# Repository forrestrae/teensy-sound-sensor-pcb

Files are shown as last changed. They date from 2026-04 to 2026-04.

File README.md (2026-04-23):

# Sound Sensor Teensy Carrier

A KiCad 9.0 carrier board for the Teensy 4.x microcontroller, designed for real-time audio sensing with USB-C Power Delivery input, 4S Li-ion battery management, I2S MEMS microphone, and LED lighting outputs.

## Features

- **USB-C Power Delivery** — TPS25751 PD controller with EEPROM configuration; accepts standard 5 V USB or negotiated PD voltages
- **4S Li-ion Battery System** — BQ25798 charger, BQ7791500 multi-cell protection (30 A rated), and Infineon N-channel disconnect FET
- **Regulated Power Rails** — 5 V and 3.3 V via TPS54538 synchronous buck converter
- **I2S MEMS Microphone** — TDK ICS-43434 with direct I2S2 connection to Teensy
- **Dual LED Drivers** — TPS923652 (white, ADIM + PWM) and TPS92200D2 (UV-A 3535, PWM)
- **Multi-board panel** — PCB ships as a panel; individual sub-boards extracted with kikit

## Hardware Overview

### Schematic Architecture

The design uses KiCad hierarchical sheets:

| Page | Sub-sheet | File |
|---|---|---|
| 1 | Top level | `Sound Sensor Teensy Carrier.kicad_sch` |
| 2 | USB-C Connector | `usb-c-connector.kicad_sch` |
| 3 | USB-PD Controller | `usb-pd-controller.kicad_sch` |
| 4 | Battery Charger | `battery-charger.kicad_sch` |
| 5 | DC Converters | `dc-converters.kicad_sch` |
| 6 | MCU | `mcu.kicad_sch` |
| 7 | Battery Protector | `battery_protector.kicad_sch` |
| 8 | Mic Boom | `mic_boom.kicad_sch` |
| 9 | WL-SUMW UV LED Board | `wl-sumw_uv_led_board.kicad_sch` |
| 10 | White LED Board | `white_led_board.kicad_sch` |

### Power Architecture

```
USB-C (5 V–20 V PD)
  └─ TPS25751 USB-PD Controller
       └─ VBUS / +5 V rail
            ├─ TPS54538 Buck → +3.3 V (MCU, logic, microphone)
            └─ BQ25798 Charger → 4S Li-ion pack (14.8 V–16.8 V)
                                    └─ BQ7791500 Protection
```

### Key Components

| Function | Part | Manufacturer |
|---|---|---|
| USB-PD Controller | TPS25751DREFR | Texas Instruments |
| PD Config EEPROM | 24LC256-I/SN | Microchip |
| Battery Charger | BQ25798RQMR | Texas Instruments |
| Battery Protector | BQ7791500PWR | Texas Instruments |
| Disconnect FET | IQDH35N03LM5ATMA1 | Infineon |
| NTC Thermistor | 103AT-2 (10 kΩ) | Semitec |
| Buck Converter | TPS54538RQFR | Texas Instruments |
| MEMS Microphone | ICS-43434 | TDK |
| White LED Driver | TPS923652DRRR | Texas Instruments |
| UV LED Driver | TPS92200D2DDCR | Texas Instruments |

### MCU Connections (Teensy 4.x)

| Signal | Teensy Interface | Description |
|---|---|---|
| `I2S.BCLK` / `SD` / `WS` | I2S2 | ICS-43434 microphone |
| `MCU_I2C.SCL/SDA/IRQ` | I2C | Charger + PD controller |
| `LED.ONSET_EN/ADIM` | PWM | White LED onset channel |
| `LED.BEAT1_EN/ADIM` | PWM | White LED beat channel 1 |
| `LED.BEAT2_EN/ADIM` | PWM | White LED beat channel 2 |

## Repository Structure

```
Sound Sensor Teensy Carrier Kicad/
├── Sound Sensor Teensy Carrier.kicad_pro   # Project file
├── Sound Sensor Teensy Carrier.kicad_pcb   # PCB layout (panel)
├── Sound Sensor Teensy Carrier.kicad_sch   # Top-level schematic
├── battery-charger.kicad_sch
├── battery_protector.kicad_sch
├── dc-converters.kicad_sch
├── mcu.kicad_sch
├── mic_boom.kicad_sch
├── usb-c-connector.kicad_sch
├── usb-pd-controller.kicad_sch
├── white_led_board.kicad_sch
├── wl-sumw_uv_led_board.kicad_sch
├── seperate.zsh                            # kikit panel extraction script
├── ibom.config.ini                         # Interactive BOM config
└── freerouting.dsn                         # Freerouting export
```

## Tools & Dependencies

| Tool | Purpose | Install |
|---|---|---|
| [KiCad 9.0](https://www.kicad.org/) | EDA (schematic + layout) | kicad.org |
| [kikit](https://github.com/yaqwsx/KiKit) | Panel sub-board extraction | `pip install kikit` |
| [InteractiveHtmlBom](https://github.com/openscopeproject/InteractiveHtmlBom) | BOM generation | KiCad plugin manager |

## Sub-board Extraction

The PCB is laid out as a panel. `seperate.zsh` uses `kikit separate` to extract individual sub-boards by board-array reference designator into `output/<name>/`:

```zsh
./seperate.zsh
```

Edit the script to enable/disable specific boards (B1–B6). Extracted boards are written to `output/<board-name>/<board-name>.kicad_pcb`.

## BOM Generation

Open the project in KiCad and run the **Interactive HTML BOM** plugin. Output lands in `bom/ibom.html` per `ibom.config.ini`. Key BOM fields: Value, Footprint, MPN, Manufacturer, Datasheet, Category.

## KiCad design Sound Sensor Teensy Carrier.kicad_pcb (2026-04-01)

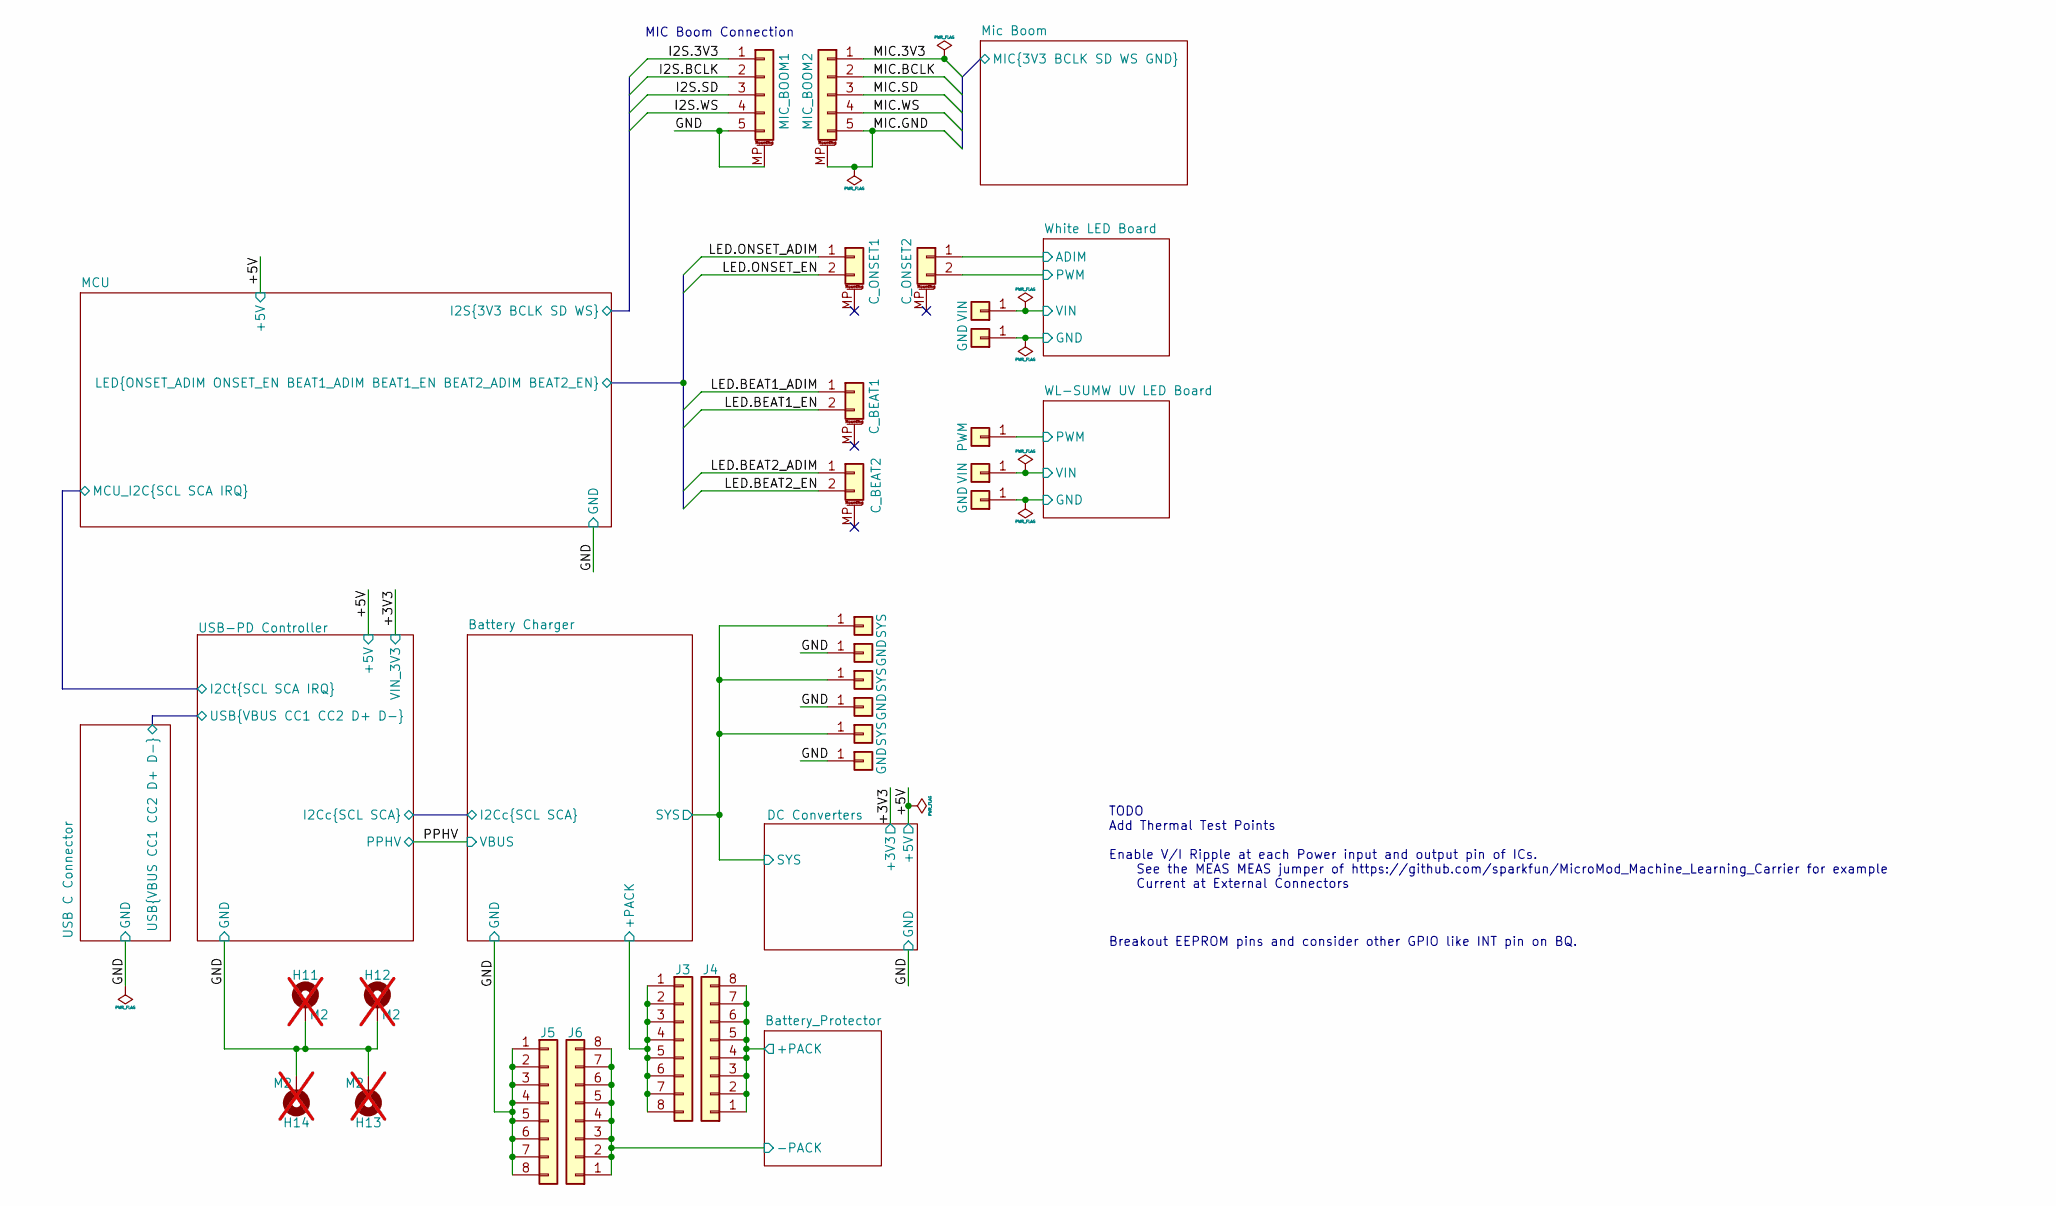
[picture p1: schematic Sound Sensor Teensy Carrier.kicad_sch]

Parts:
C_BEAT1: BEAT1; Molex_Pico-Clasp_203558-0207_1x02-1MP_P1.00mm_Horizontal; MPN 203558-0207; Mouser SPN 538-203558-0207
C_BEAT2: BEAT2; Molex_Pico-Clasp_203558-0207_1x02-1MP_P1.00mm_Horizontal; MPN 203558-0207; Mouser SPN 538-203558-0207
C_ONSET1, C_ONSET2: ONSET; Molex_Pico-Clasp_203558-0207_1x02-1MP_P1.00mm_Horizontal; MPN 203558-0207; Mouser SPN 538-203558-0207
H3, H5, H7: SYS; SolderWirePad_1x01_SMD_2x4mm
H4, H6, H8, H24, H26: GND; SolderWirePad_1x01_SMD_2x4mm
H11, H12, H13, H14: M2; StandOff_M2x5mm; MPN 971050244; Mouser SPN 710-971050244; not fitted
H23, H25: VIN; SolderWirePad_1x01_SMD_2x4mm
H27: PWM; SolderWirePad_1x01_SMD_1.5x3mm
J3: +PACK; SAMTEC_TMMH-104-05-F-DV; MPN TMMH-104-05-F-DV; Mouser SPN 200-TMMH10405FDV
J4: +PACK; SAMTEC_CLT-104-02-F-D; MPN CLT-104-02-F-D; Mouser SPN 200-CLT10402FD
J5: -PACK; SAMTEC_TMMH-104-05-F-DV; MPN TMMH-104-05-F-DV; Mouser SPN 200-TMMH10405FDV
J6: -PACK; SAMTEC_CLT-104-02-F-D; MPN CLT-104-02-F-D; Mouser SPN 200-CLT10402FD
MIC_BOOM1: MIC; Molex_Pico-Clasp_202396-0507_1x05-1MP_P1.00mm_Horizontal; MPN 203562-0505; Mouser SPN 538-203562-0505
MIC_BOOM2: MIC; Molex_Pico-Clasp_501331-0507_1x05-1MP_P1.00mm_Vertical; MPN 504449-0507; Mouser SPN 538-504449-0507

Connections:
/Battery Charger/+PACK: J3.1, J3.2, J3.3, J3.4, J3.5, J3.6, J3.7, J3.8; also elsewhere on the board
/Battery Charger/SYS: H3.1, H5.1, H7.1; also elsewhere on the board
/Battery_Protector/+PACK: J4.1, J4.2, J4.3, J4.4, J4.5, J4.6, J4.7, J4.8; also elsewhere on the board
/Battery_Protector/-PACK: J6.1, J6.2, J6.3, J6.4, J6.5, J6.6, J6.7, J6.8; also elsewhere on the board
/GND: H4.1, H6.1, H8.1, H11.1, H12.1, H13.1, H14.1, J5.1, J5.2, J5.3, J5.4, J5.5, J5.6, J5.7, J5.8, MIC_BOOM1.5, MIC_BOOM1.MP (MountPin); also elsewhere on the board
/MCU/I2S.3V3: MIC_BOOM1.1; also elsewhere on the board
/MCU/I2S.BCLK: MIC_BOOM1.2; also elsewhere on the board
/MCU/I2S.SD: MIC_BOOM1.3; also elsewhere on the board
/MCU/I2S.WS: MIC_BOOM1.4; also elsewhere on the board
/MCU/LED.BEAT1_ADIM: C_BEAT1.1; also elsewhere on the board
/MCU/LED.BEAT1_EN: C_BEAT1.2; also elsewhere on the board
/MCU/LED.BEAT2_ADIM: C_BEAT2.1; also elsewhere on the board
/MCU/LED.BEAT2_EN: C_BEAT2.2; also elsewhere on the board
/MCU/LED.ONSET_ADIM: C_ONSET1.1; also elsewhere on the board
/MCU/LED.ONSET_EN: C_ONSET1.2; also elsewhere on the board
/Mic Boom/MIC.3V3: MIC_BOOM2.1; also elsewhere on the board
/Mic Boom/MIC.BCLK: MIC_BOOM2.2; also elsewhere on the board
/Mic Boom/MIC.GND: MIC_BOOM2.5, MIC_BOOM2.MP (MountPin); also elsewhere on the board
/Mic Boom/MIC.SD: MIC_BOOM2.3; also elsewhere on the board
/Mic Boom/MIC.WS: MIC_BOOM2.4; also elsewhere on the board
/WL-SUMW UV LED Board/GND: H26.1; also elsewhere on the board
/WL-SUMW UV LED Board/PWM: H27.1; also elsewhere on the board
/WL-SUMW UV LED Board/VIN: H25.1; also elsewhere on the board
/White LED Board/ADIM: C_ONSET2.1; also elsewhere on the board
/White LED Board/GND: H24.1; also elsewhere on the board
/White LED Board/PWM: C_ONSET2.2; also elsewhere on the board
/White LED Board/VIN: H23.1; also elsewhere on the board

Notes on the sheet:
MIC Boom Connection
TODO Add Thermal Test Points Enable V/I Ripple at each Power input and output pin of ICs. See the MEAS MEAS jumper of https://github.com/sparkfun/MicroMod_Machine_Learning_Carrier for example Current at External Connectors Breakout EEPROM pins and consider other GPIO like INT pin on BQ.

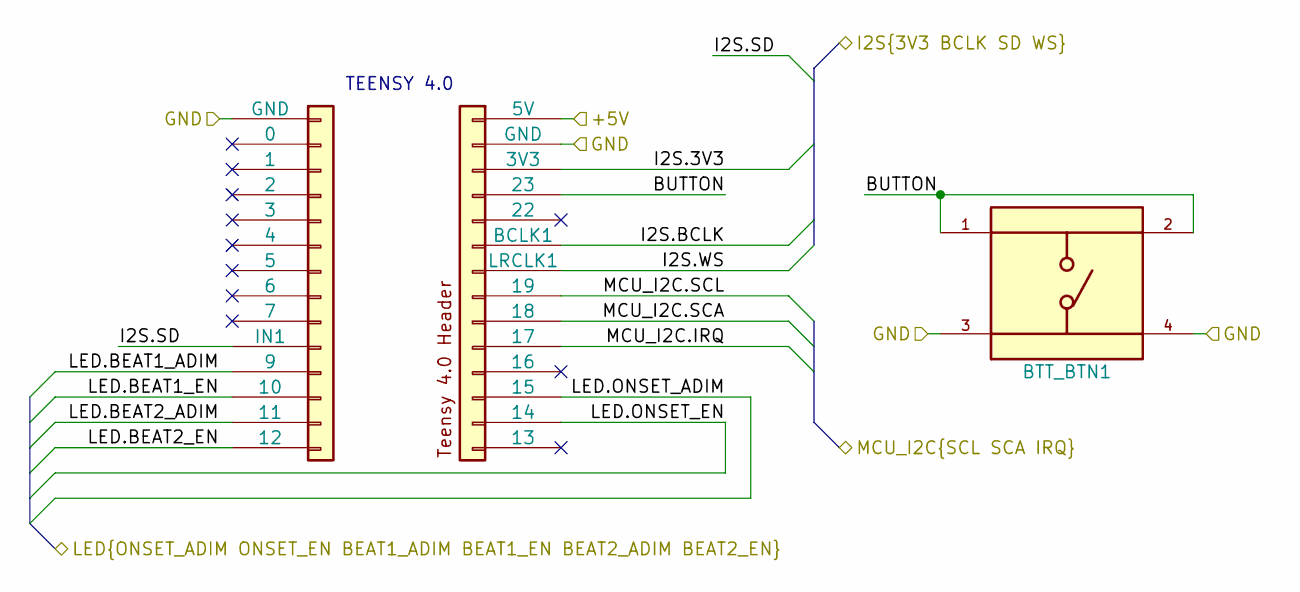
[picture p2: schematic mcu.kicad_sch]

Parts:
BTT_BTN1: 13mm; SW_TS02-66-130-BK-260-SCR-D; PARTREV 1.0; Mouser SPN 179-TS0266130BK260SC
C_TEENSY1: Teensy_4.0_Pin_Header; MPN SLW-150-01-G-S

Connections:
/+5V: C_TEENSY1.5V; also elsewhere on the board
/GND: BTT_BTN1.3, BTT_BTN1.4, C_TEENSY1.G0 (GND), C_TEENSY1.G1 (GND); also elsewhere on the board
/MCU/BUTTON: BTT_BTN1.1, BTT_BTN1.2, C_TEENSY1.23
/MCU/I2S.3V3: C_TEENSY1.3V3; also elsewhere on the board
/MCU/I2S.BCLK: C_TEENSY1.21 (BCLK1); also elsewhere on the board
/MCU/I2S.SD: C_TEENSY1.8 (IN1); also elsewhere on the board
/MCU/I2S.WS: C_TEENSY1.20 (LRCLK1); also elsewhere on the board
/MCU/LED.BEAT1_ADIM: C_TEENSY1.9; also elsewhere on the board
/MCU/LED.BEAT1_EN: C_TEENSY1.10; also elsewhere on the board
/MCU/LED.BEAT2_ADIM: C_TEENSY1.11; also elsewhere on the board
/MCU/LED.BEAT2_EN: C_TEENSY1.12; also elsewhere on the board
/MCU/LED.ONSET_ADIM: C_TEENSY1.15; also elsewhere on the board
/MCU/LED.ONSET_EN: C_TEENSY1.14; also elsewhere on the board
/MCU/MCU_I2C.IRQ: C_TEENSY1.17; also elsewhere on the board
/MCU/MCU_I2C.SCA: C_TEENSY1.18; also elsewhere on the board
/MCU/MCU_I2C.SCL: C_TEENSY1.19; also elsewhere on the board

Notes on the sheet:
TEENSY 4.0

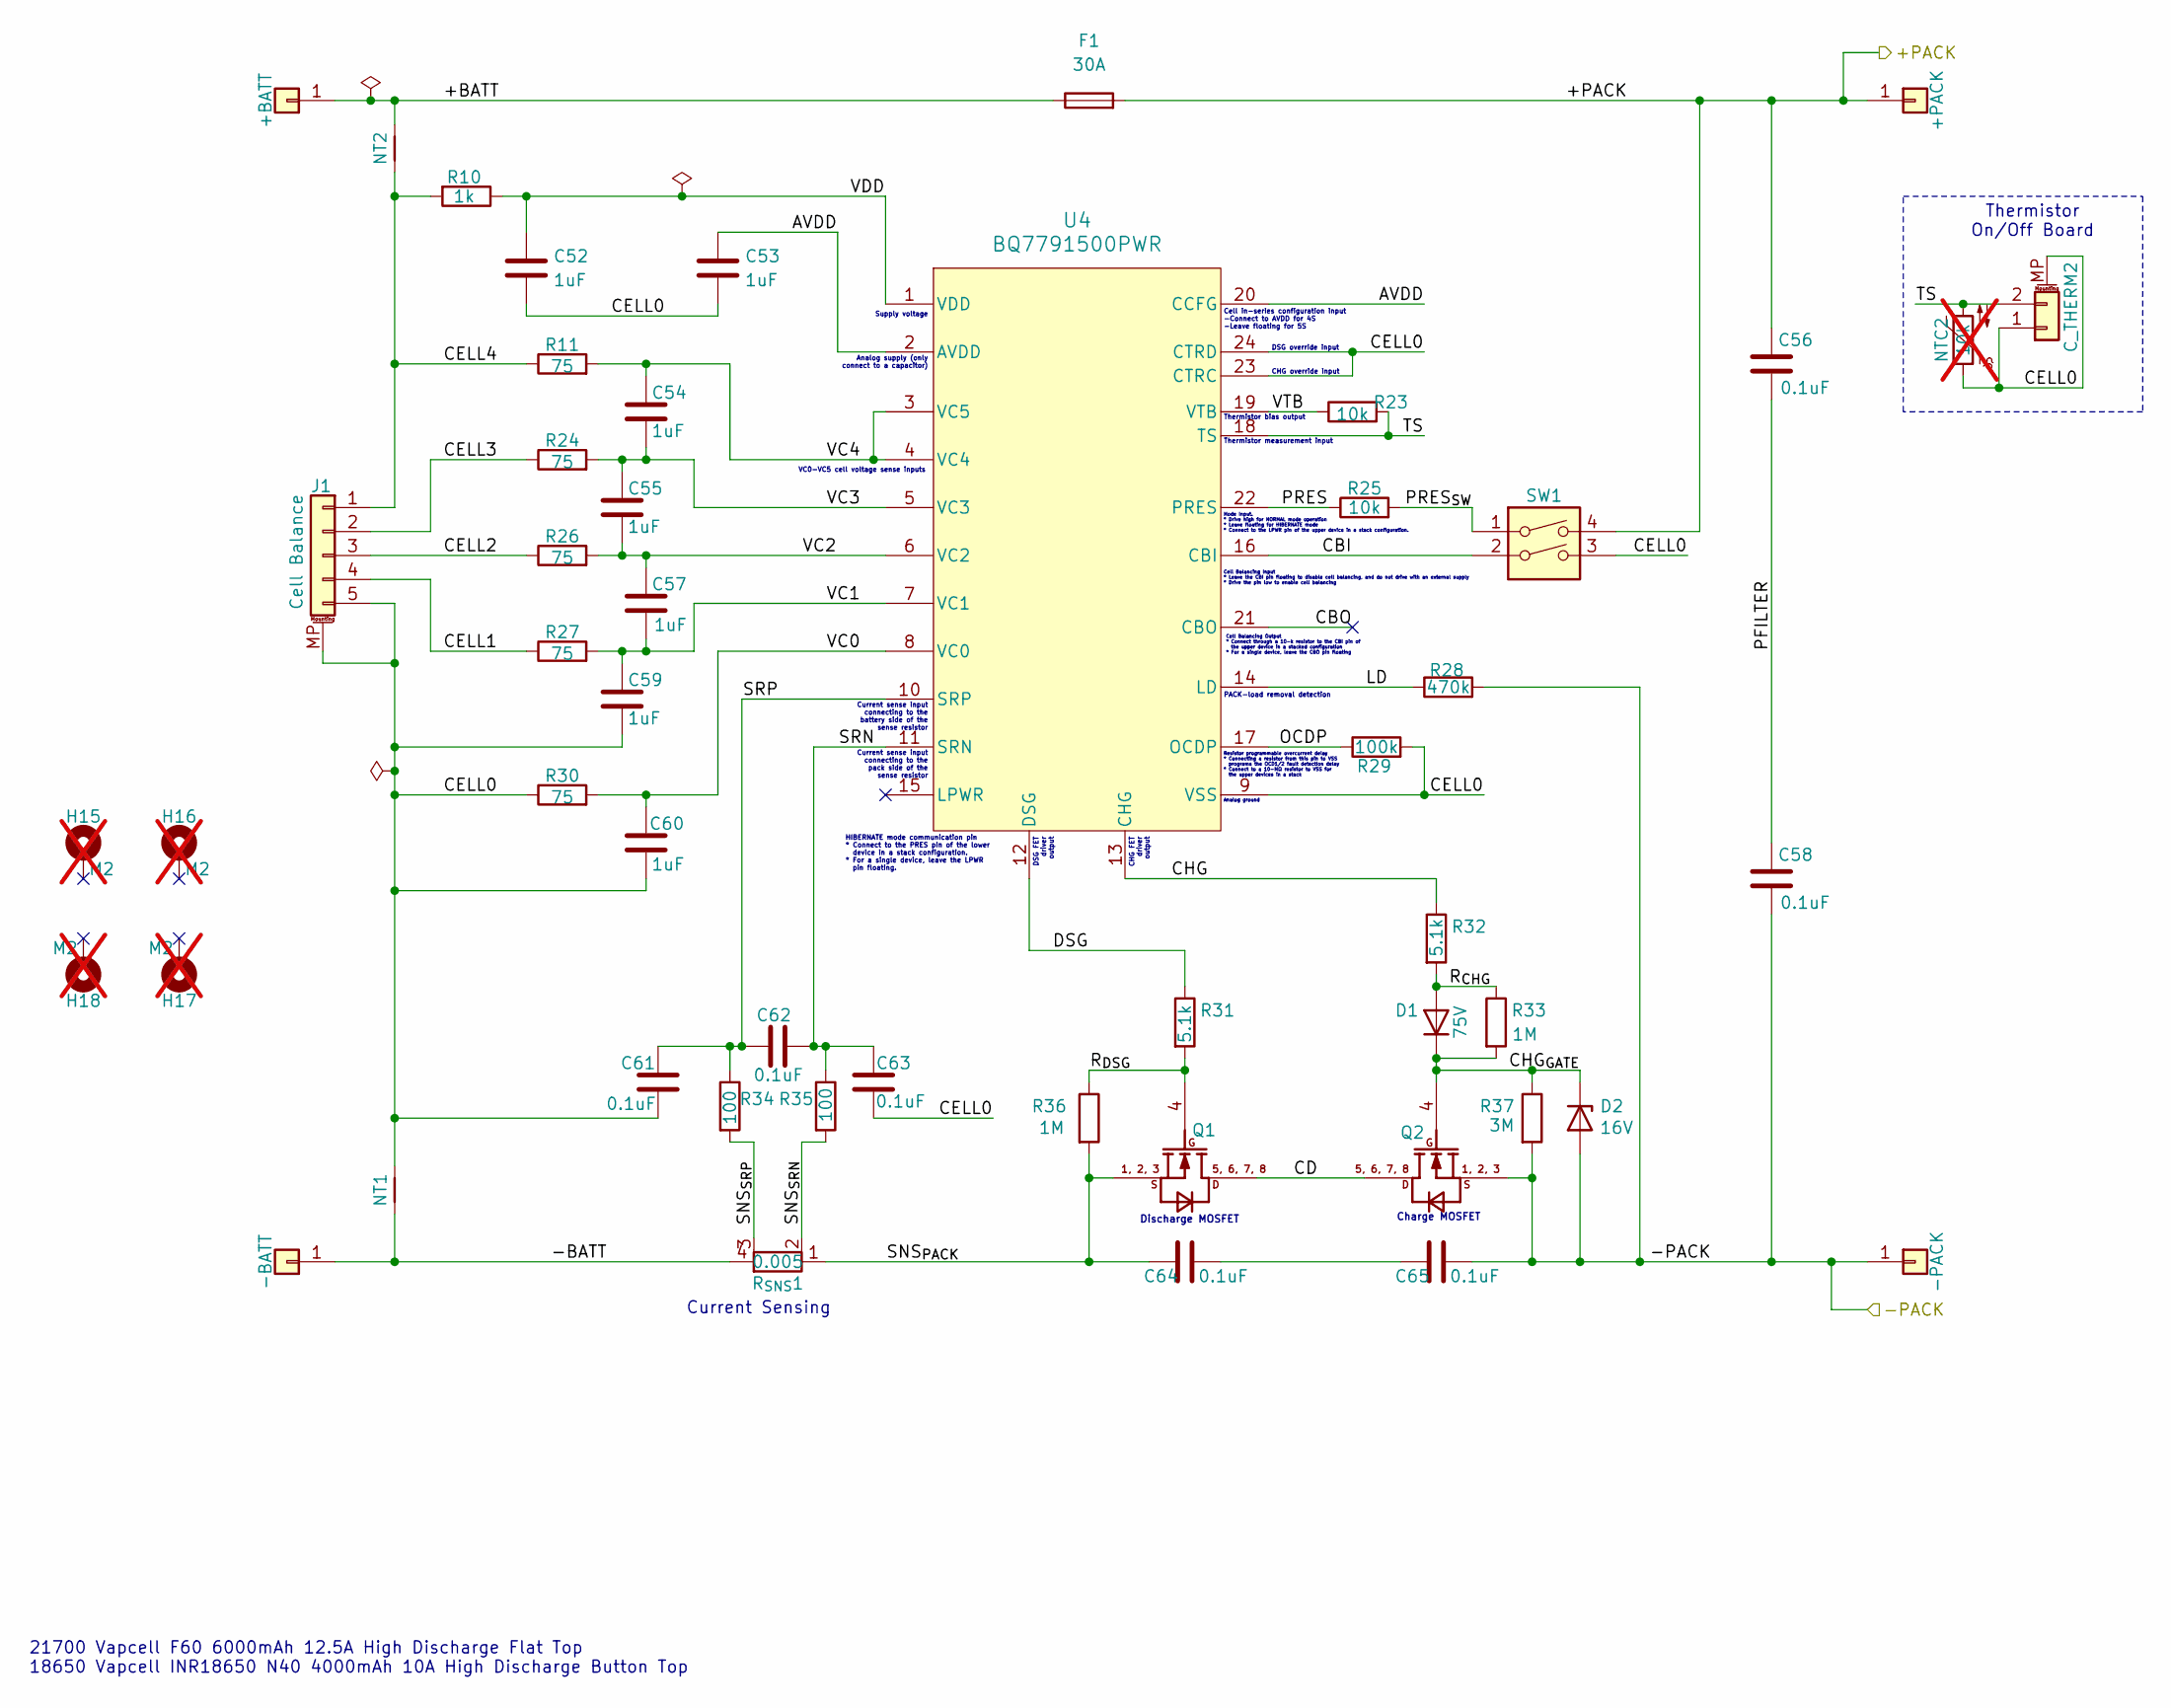
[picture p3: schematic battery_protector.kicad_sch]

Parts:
C52, C53, C54, C55, C57, C59, C60: 1uF; C_0603_1608Metric; MPN 06035C105KAT2A; Farnell SPN 4155078
C56, C58, C61, C62, C63, C64, C65: 0.1uF; C_0603_1608Metric; MPN GCM188R71H104KA57J; Mouser SPN 81-GCM188R71H104KA7J
C_THERM2: NTC; Molex_Pico-Clasp_203558-0207_1x02-1MP_P1.00mm_Horizontal; MPN 203558-0207; Mouser SPN 538-203558-0207
D1: 75V; D_SOD-323F; MPN CDSF4148; Mouser SPN 750-CDSF4148
D2: 16V; D_SOD-323; MPN BZX384C16-G3-08; Mouser SPN 78-BZX384C16-G3-08
F1: 30A; FUSE_SF-3812FG3000T-2; MPN SF-3812FG3000T-2; Mouser SPN 652-SF-3812FG3000T-2
H1: +BATT; SolderWirePad_1x01_SMD_4x8mm
H2: -BATT; SolderWirePad_1x01_SMD_4x8mm
H9: +PACK; SolderWirePad_1x01_SMD_4x8mm
H10: -PACK; SolderWirePad_1x01_SMD_4x8mm
H15, H16, H17, H18: M2; StandOff_M2x5mm; MPN 971050244; Mouser SPN 710-971050244; not fitted
J1: Cell Balance; Molex_Pico-Clasp_202396-0507_1x05-1MP_P1.00mm_Horizontal; MPN 203562-0505; Mouser SPN 538-203562-0505
NT1, NT2: NetTie_2; NetTie-2_SMD_Pad0.5mm
NTC2: 10k; R_0603_1608Metric; MPN NTCGS163JX103DT8; DigiKey SPN 445-NTCGS163JX103DT8CT-ND; not fitted
Q1, Q2: IQDH35N03LM5; IFX-PG-TSON-8-9-V; MPN IQDH35N03LM5ATMA1; DigiKey SPN 448-IQDH35N03LM5ATMA1TR-ND
R10: 1k; R_0603_1608Metric; MPN RCS06031K00FKEA; DigiKey SPN 541-2788-1-ND
R11, R24, R26, R27, R30: 75; R_0603_1608Metric; MPN RCS060375R0FKEA; Farnell SPN 4140951
R23, R25: 10k; R_0603_1608Metric; MPN RCS060310K0FKEA; Mouser SPN 71-RCS060310K0FKEA
R28: 470k; R_0603_1608Metric; MPN CRCW0603470KFKEA; Farnell SPN 1469814
R29: 100k; R_0603_1608Metric; MPN RCS0603100KFKEA; Mouser SPN 71-RCS0603100KFKEA
R31, R32: 5.1k; R_0603_1608Metric; MPN RCS06035K10FKEA; Farnell SPN 4140947
R33, R36: 1M; R_0603_1608Metric; MPN RCS06031M00FKEA; Farnell SPN 4140931
R34, R35: 100; R_0603_1608Metric; MPN RCS0603100RFKEA; Mouser SPN 71-RCS0603100RFKEA
R37: 3M; R_0603_1608Metric; MPN CRCW06033M00FKEA; Farnell SPN 1469650
R_{SNS}1: 0.005; R_Shunt_Vishay_WSL3637_9194Metric_T2.18mm; MPN WSL36375L000DEA; Farnell SPN 4552590
SW1: DIP; SW_DIP_SPSTx02_Slide_Omron_A6H-2101_W6.15mm_P1.27mm; MPN A6H-2101; Farnell SPN 1960885
U4: BQ7791500PWR; PW24_TEX; MPN BQ7791500PWR; DigiKey SPN 296-50995-2-ND

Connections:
/Battery_Protector/+BATT: F1.1, H1.1, NT2.2
/Battery_Protector/+PACK: C56.1, F1.2, H9.1, SW1.4; also elsewhere on the board
/Battery_Protector/-BATT: H2.1, NT1.1, R_{SNS}1.4
/Battery_Protector/-PACK: C58.2, C65.2, D2.2 (A), H10.1, Q2.1 (SOURCE), Q2.2 (SOURCE), Q2.3 (SOURCE), R28.2, R37.2; also elsewhere on the board
/Battery_Protector/AVDD: C53.1, U4.2 (AVDD), U4.20 (CCFG)
/Battery_Protector/CBI: SW1.2, U4.16 (CBI)
/Battery_Protector/CBO: U4.21 (CBO)
/Battery_Protector/CD: Q1.5 (DRAIN), Q1.6 (DRAIN), Q1.7 (DRAIN), Q1.8 (DRAIN), Q2.5 (DRAIN), Q2.6 (DRAIN), Q2.7 (DRAIN), Q2.8 (DRAIN)
/Battery_Protector/CELL0: C52.2, C53.2, C59.2, C60.2, C61.2, C63.1, C_THERM2.1, C_THERM2.MP (MountPin), J1.5, J1.MP (MountPin), NT1.2, NTC2.1, R29.2, R30.1, SW1.3, U4.9 (VSS), U4.23 (CTRC), U4.24 (CTRD)
/Battery_Protector/CELL1: J1.4, R27.1
/Battery_Protector/CELL2: J1.3, R26.1
/Battery_Protector/CELL3: J1.2, R24.1
/Battery_Protector/CELL4: J1.1, NT2.1, R10.2, R11.1
/Battery_Protector/CHG: R32.1, U4.13 (CHG)
/Battery_Protector/CHG_{GATE}: D1.1 (K), D2.1 (K), Q2.4 (GATE), R33.2, R37.1
/Battery_Protector/DSG: R31.1, U4.12 (DSG)
/Battery_Protector/LD: R28.1, U4.14 (LD)
/Battery_Protector/OCDP: R29.1, U4.17 (OCDP)
/Battery_Protector/PFILTER: C56.2, C58.1
/Battery_Protector/PRES: R25.1, U4.22 (PRES)
/Battery_Protector/PRES_{SW}: R25.2, SW1.1
/Battery_Protector/R_{CHG}: D1.2 (A), R32.2, R33.1
/Battery_Protector/R_{DSG}: Q1.4 (GATE), R31.2, R36.1
/Battery_Protector/SNS_{PACK}: C64.1, Q1.1 (SOURCE), Q1.2 (SOURCE), Q1.3 (SOURCE), R36.2, R_{SNS}1.1
/Battery_Protector/SNS_{SRN}: R35.2, R_{SNS}1.2
/Battery_Protector/SNS_{SRP}: R34.2, R_{SNS}1.3
/Battery_Protector/SRN: C62.2, C63.2, R35.1, U4.11 (SRN)
/Battery_Protector/SRP: C61.1, C62.1, R34.1, U4.10 (SRP)
/Battery_Protector/TS: C_THERM2.2, NTC2.2, R23.2, U4.18 (TS)
/Battery_Protector/VC0: C60.1, R30.2, U4.8 (VC0)
/Battery_Protector/VC1: C57.2, C59.1, R27.2, U4.7 (VC1)
/Battery_Protector/VC2: C55.2, C57.1, R26.2, U4.6 (VC2)
/Battery_Protector/VC3: C54.2, C55.1, R24.2, U4.5 (VC3)
/Battery_Protector/VC4: C54.1, R11.2, U4.3 (VC5), U4.4 (VC4)
/Battery_Protector/VDD: C52.1, R10.1, U4.1 (VDD)
/Battery_Protector/VTB: R23.1, U4.19 (VTB)
unnamed: C64.2, C65.1

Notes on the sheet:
Thermistor On/Off Board
Cell Balancing Output * Connect through a 10-k resistor to the CBI pin of the upper device in a stacked configuration * For a single device, leave the CBO pin floating
Analog ground
DSG override input
HIBERNATE mode communication pin * Connect to the PRES pin of the lower device in a stack configuration. * For a single device, leave the LPWR pin floating.
Analog supply (only connect to a capacitor)
PACK-load removal detection
Resistor programmable overcurrent delay * Connecting a resistor from this pin to VSS programs the OCD1/2 fault detection delay * Connect to a 10-MΩ resistor to VSS for the upper devices in a stack
Current Sensing
21700 Vapcell F60 6000mAh 12.5A High Discharge Flat Top 18650 Vapcell INR18650 N40 4000mAh 10A High Discharge Button Top
DSG FET driver output
Cell in-series configuration input -Connect to AVDD for 4S -Leave floating for 5S
Charge MOSFET
Cell Balancing Input * Leave the CBI pin floating to disable cell balancing, and do not drive with an external supply * Drive the pin low to enable cell balancing
Discharge MOSFET
Thermistor measurement input
CHG FET driver output
Mode Input. * Drive high for NORMAL mode operation * Leave floating for HIBERNATE mode * Connect to the LPWR pin of the upper device in a stack configuration.
Current sense input connecting to the pack side of the sense resistor
VC0-VC5 cell voltage sense inputs
Current sense input connecting to the battery side of the sense resistor
Supply voltage
Thermistor bias output
CHG override input

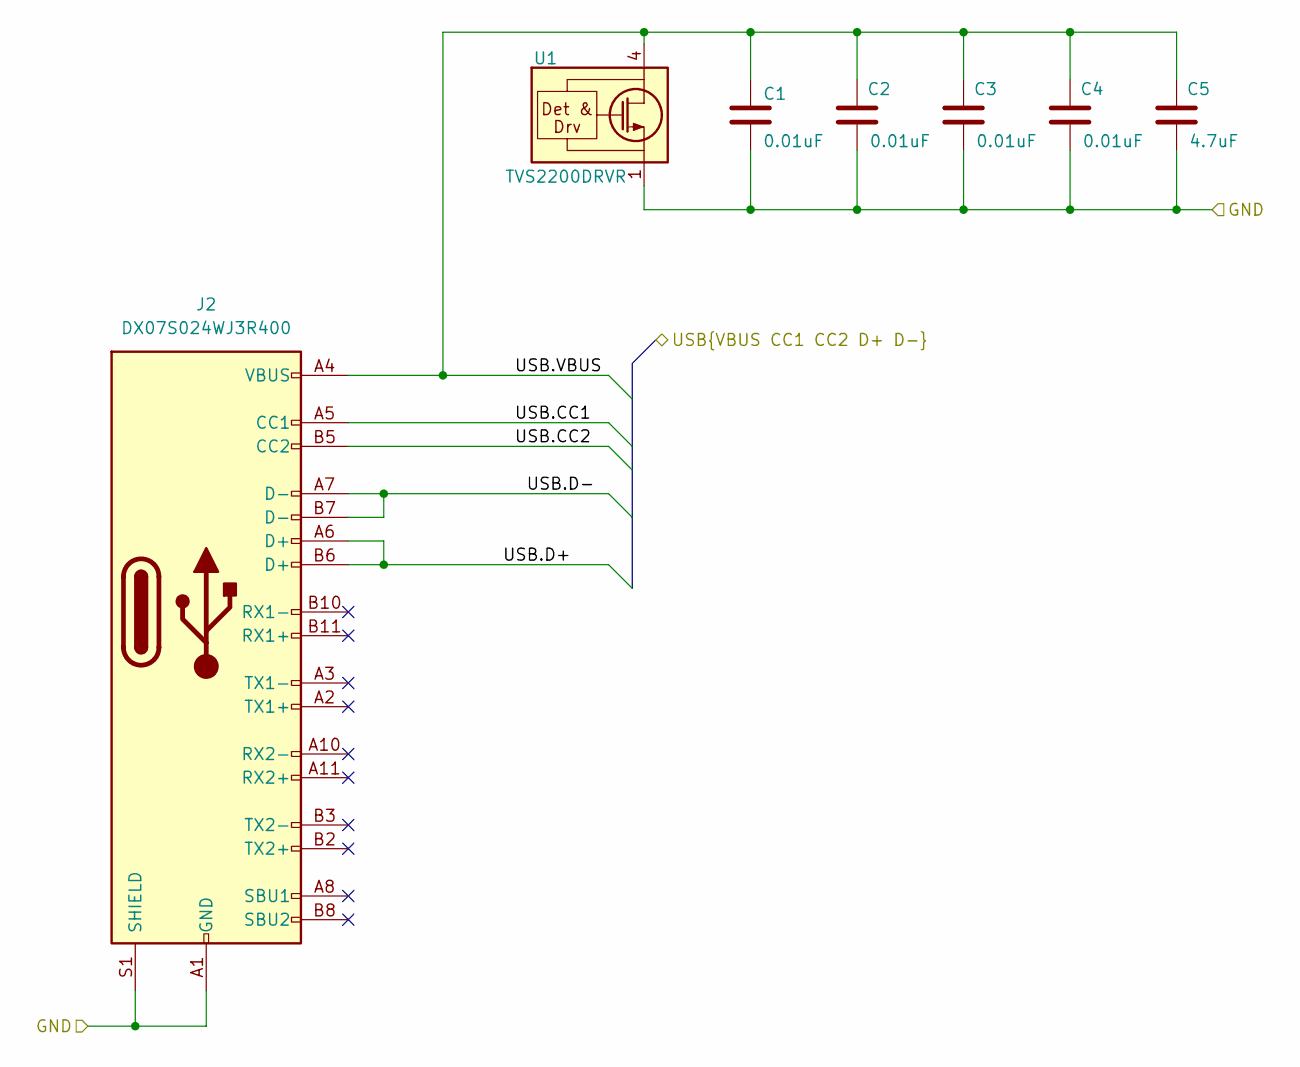
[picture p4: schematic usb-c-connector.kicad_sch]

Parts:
C1, C2, C3, C4: 0.01uF; C_0603_1608Metric; MPN GCM1885C1H103GA16D; Mouser SPN 81-GCM1885C1H103GA6D
C5: 4.7uF; C_0603_1608Metric; MPN GRM188R6YA475KE15D; Mouser SPN 81-GRM188R6YA475KE5D
J2: DX07S024WJ3R400; USB_C_Receptacle_JAE_DX07S024WJ3R400; MPN DX07S024WJ3R400; Mouser SPN 656-DX07S0024WJ3R400
U1: TVS2200DRVR; WSON-6-1EP_2x2mm_P0.65mm_EP1x1.6mm; MPN TVS2200DRVR; Mouser SPN 595-TVS2200DRVR

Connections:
/GND: C1.2, C2.2, C3.2, C4.2, C5.2, J2.A1 (GND), J2.A12 (GND), J2.B1 (GND), J2.B12 (GND), J2.S1 (SHIELD), U1.1 (GND), U1.2 (GND), U1.3 (GND), U1.7 (GND); also elsewhere on the board
/USB C Connector/USB.CC1: J2.A5 (CC1); also elsewhere on the board
/USB C Connector/USB.CC2: J2.B5 (CC2); also elsewhere on the board
/USB C Connector/USB.D+: J2.A6 (D+), J2.B6 (D+); also elsewhere on the board
/USB C Connector/USB.D-: J2.A7 (D-), J2.B7 (D-); also elsewhere on the board
/USB C Connector/USB.VBUS: C1.1, C2.1, C3.1, C4.1, C5.1, J2.A4 (VBUS), J2.A9 (VBUS), J2.B4 (VBUS), J2.B9 (VBUS), U1.4 (IN), U1.5 (IN), U1.6 (IN); also elsewhere on the board

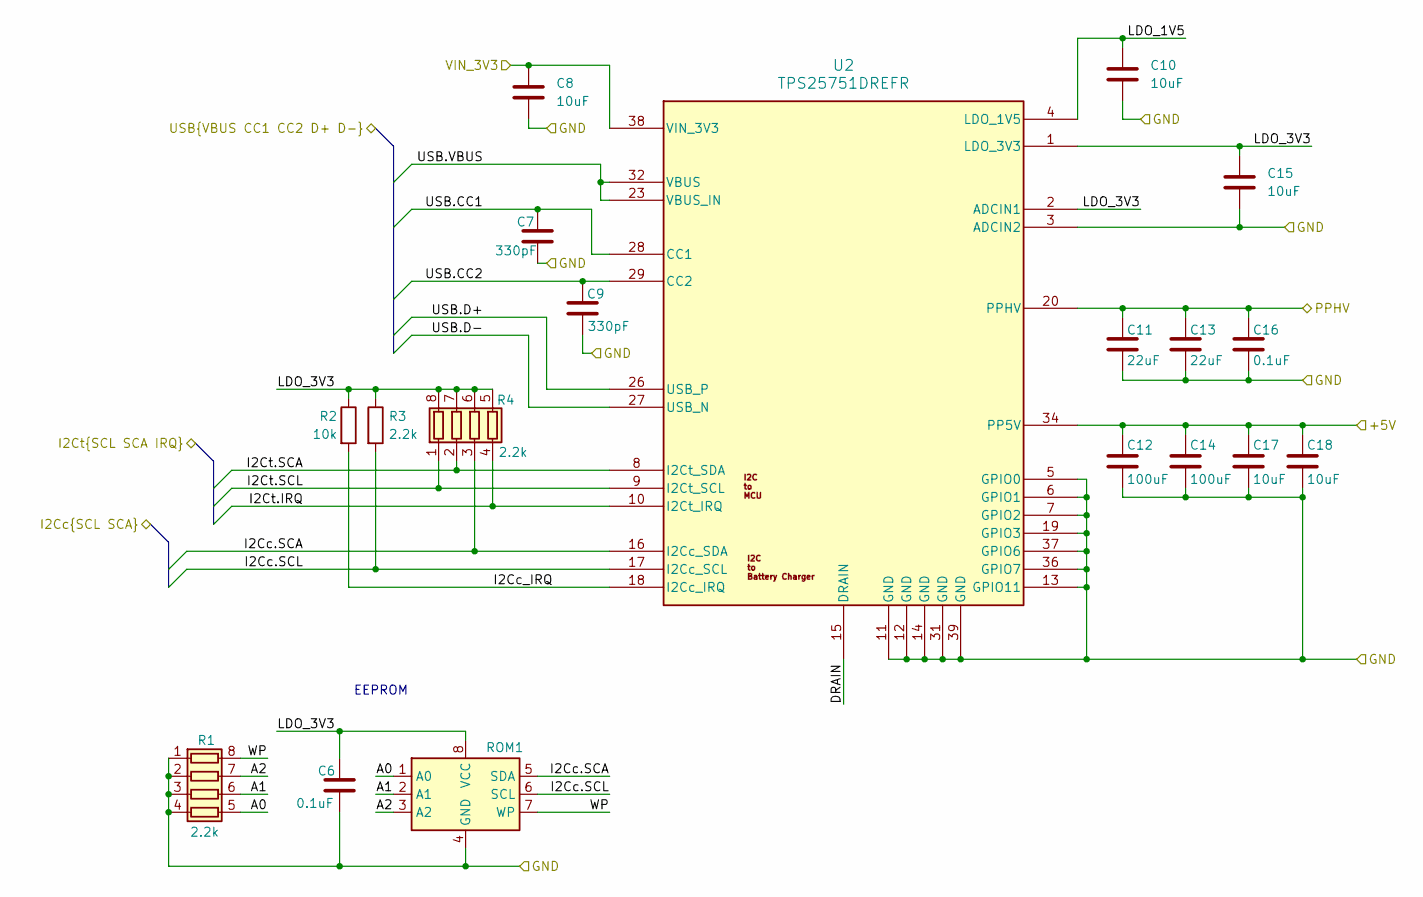
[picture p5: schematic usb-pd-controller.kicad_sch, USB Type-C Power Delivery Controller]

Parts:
C6, C16: 0.1uF; C_0603_1608Metric; MPN GCM188R71H104KA57J; Mouser SPN 81-GCM188R71H104KA7J
C7, C9: 330pF; C_0603_1608Metric; MPN VJ0603A331FXACW1BC; Mouser SPN 77-VJ0603A331FXACBC
C8, C10, C15, C17, C18: 10uF; C_0603_1608Metric; MPN GRM188R6YA106MA73D; Mouser SPN 81-GRM188R6YA106MA3D
C11, C13: 22uF; C_0805_2012Metric; MPN GRM21BR61E226ME44L; Mouser SPN 81-GRM21BR61E226ME4L
C12, C14: 100uF; C_1206_3216Metric; MPN CL31A107MPKNNWE; Mouser SPN 187-CL31A107MPKNNWE
R1, R4: 2.2k; R_Cat16-4; MPN CAY16-2201F4LF; Mouser SPN 652-CAY16-2201F4LF
R2: 10k; R_0603_1608Metric; MPN RCS060310K0FKEA; Mouser SPN 71-RCS060310K0FKEA
R3: 2.2k; R_0603_1608Metric; MPN RCS06032K20FKEA; Mouser SPN 71-RCS06032K20FKEA
ROM1: 24LC256-I/SN; SOIC-8_3.9x4.9mm_P1.27mm; MPN 24LC256-I/SN; Mouser SPN 579-24LC256-I/SN
U2: TPS25751DREFR; Texas_REF0038A_WQFN-38-2EP_6x4mm_P0.4; MPN TPS25751DREFR; Mouser SPN 595-TPS25751DREFR

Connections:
/+3V3: C8.1, U2.38 (VIN_3V3); also elsewhere on the board
/+5V: C12.1, C14.1, C17.1, C18.1, U2.34 (PP5V); also elsewhere on the board
/Battery Charger/I2Cc.SCA: R4.3 (R3.1), ROM1.5 (SDA), U2.16 (I2Cc_SDA); also elsewhere on the board
/Battery Charger/I2Cc.SCL: R3.2, ROM1.6 (SCL), U2.17 (I2Cc_SCL); also elsewhere on the board
/GND: C6.2, C7.2, C8.2, C9.2, C10.2, C11.2, C12.2, C13.2, C14.2, C15.2, C16.2, C17.2, C18.2, R1.1 (R1.1), R1.2 (R2.1), R1.3 (R3.1), R1.4 (R4.1), ROM1.4 (GND), U2.3 (ADCIN2), U2.5 (GPIO0), U2.6 (GPIO1), U2.7 (GPIO2), U2.11 (GND), U2.12 (GND), U2.13 (GPIO11), U2.14 (GND), U2.19 (GPIO3), U2.31 (GND), U2.36 (GPIO7), U2.37 (GPIO6), U2.39 (GND); also elsewhere on the board
/MCU/MCU_I2C.IRQ: R4.4 (R4.1), U2.10 (I2Ct_IRQ); also elsewhere on the board
/MCU/MCU_I2C.SCA: R4.2 (R2.1), U2.8 (I2Ct_SDA); also elsewhere on the board
/MCU/MCU_I2C.SCL: R4.1 (R1.1), U2.9 (I2Ct_SCL); also elsewhere on the board
/PPHV: C11.1, C13.1, C16.1, U2.20 (PPHV); also elsewhere on the board
/USB C Connector/USB.CC1: C7.1, U2.28 (CC1); also elsewhere on the board
/USB C Connector/USB.CC2: C9.1, U2.29 (CC2); also elsewhere on the board
/USB C Connector/USB.D+: U2.26 (USB_P); also elsewhere on the board
/USB C Connector/USB.D-: U2.27 (USB_N); also elsewhere on the board
/USB C Connector/USB.VBUS: U2.23 (VBUS_IN), U2.32 (VBUS); also elsewhere on the board
/USB-PD Controller/A0: R1.5 (R4.2), ROM1.1 (A0)
/USB-PD Controller/A1: R1.6 (R3.2), ROM1.2 (A1)
/USB-PD Controller/A2: R1.7 (R2.2), ROM1.3 (A2)
/USB-PD Controller/DRAIN: U2.15 (DRAIN), U2.30 (DRAIN), U2.40 (DRAIN)
/USB-PD Controller/I2Cc_IRQ: R2.2, U2.18 (I2Cc_IRQ)
/USB-PD Controller/LDO_1V5: C10.1, U2.4 (LDO_1V5)
/USB-PD Controller/LDO_3V3: C6.1, C15.1, R2.1, R3.1, R4.5 (R4.2), R4.6 (R3.2), R4.7 (R2.2), R4.8 (R1.2), ROM1.8 (VCC), U2.1 (LDO_3V3), U2.2 (ADCIN1)
/USB-PD Controller/WP: R1.8 (R1.2), ROM1.7 (WP)

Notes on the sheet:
EEPROM

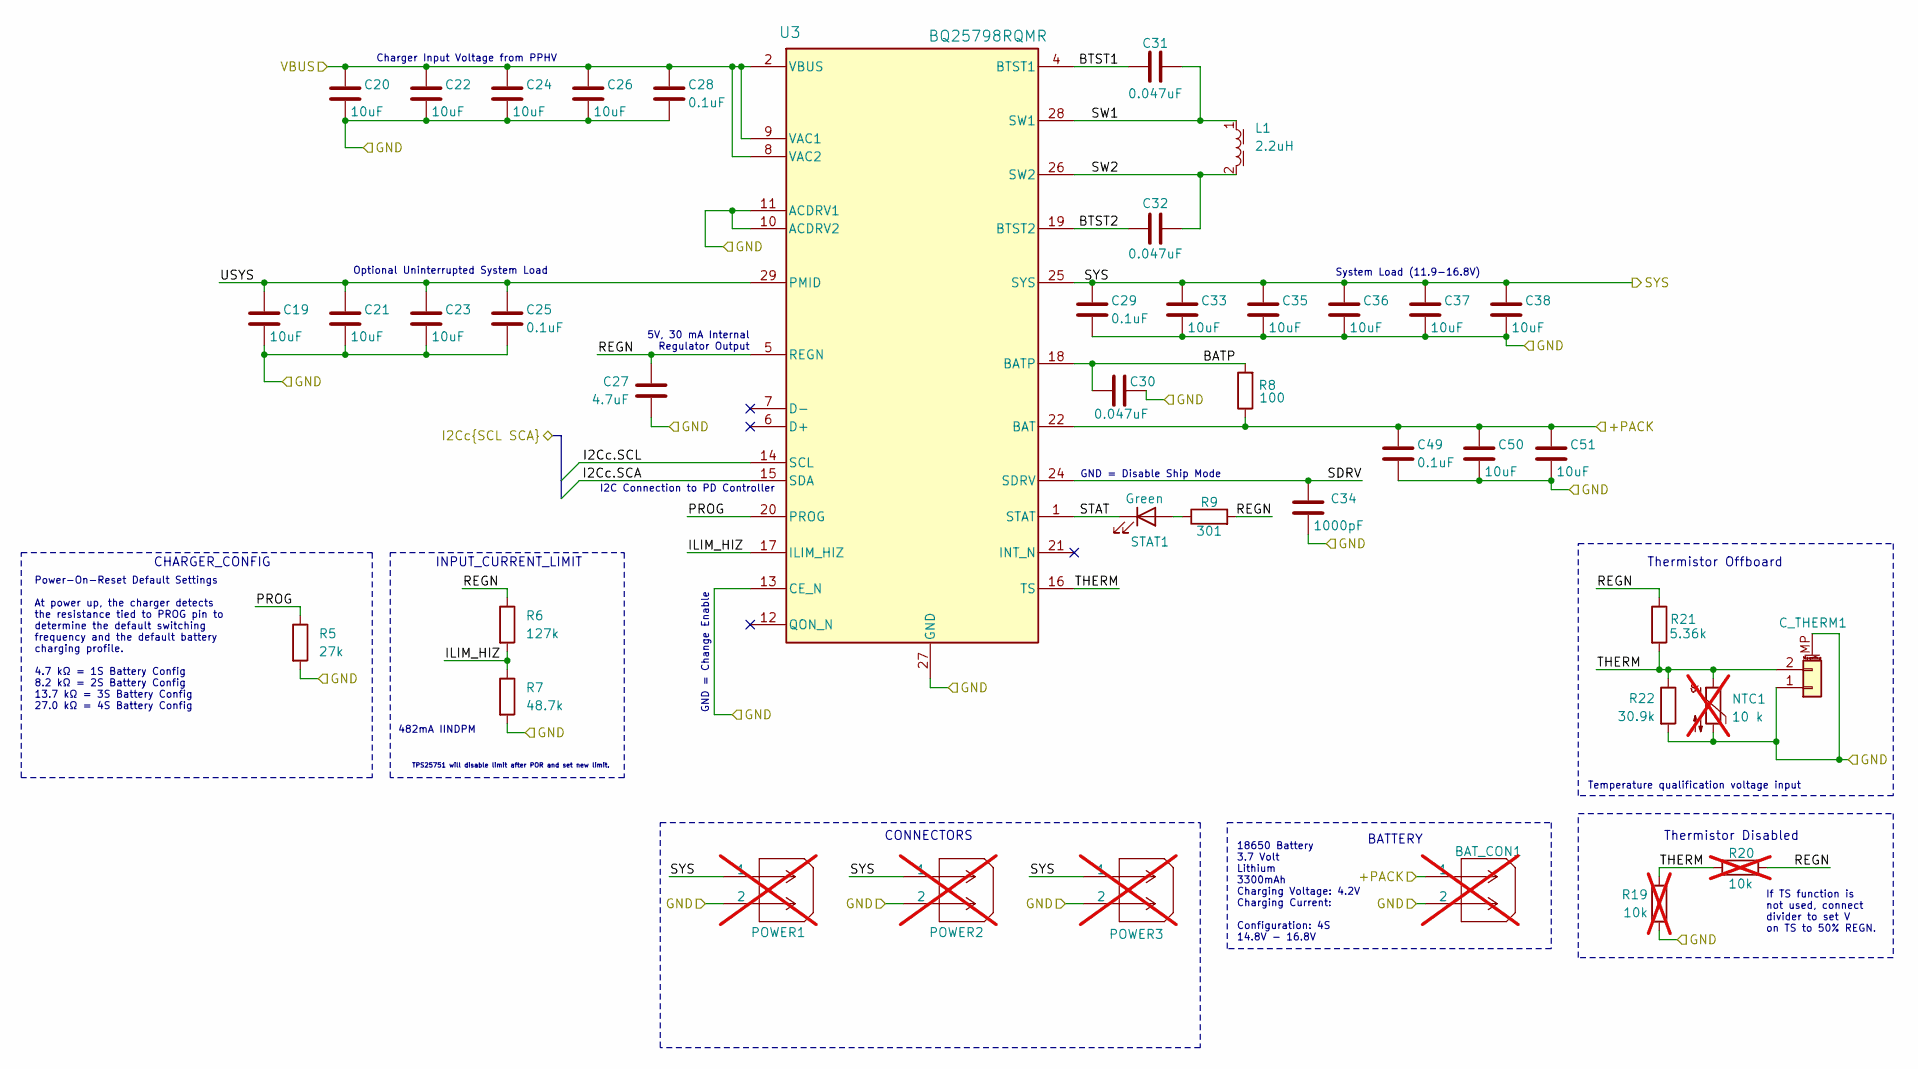
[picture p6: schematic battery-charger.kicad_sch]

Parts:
BAT_CON1: 218989-0210; CONN02_2189890210_MOL; MPN 218989-0210; Mouser SPN 538-218989-0210; not fitted
C19, C20, C21, C22, C23, C24, C26, C33, C35, C36, C37, C38, C50, C51: 10uF; C_0603_1608Metric; MPN GRM188R6YA106MA73D; Mouser SPN 81-GRM188R6YA106MA3D
C25, C28, C29, C49: 0.1uF; C_0603_1608Metric; MPN GCM188R71H104KA57J; Mouser SPN 81-GCM188R71H104KA7J
C27: 4.7uF; C_0603_1608Metric; MPN GRM188R6YA475KE15D; Mouser SPN 81-GRM188R6YA475KE5D
C30, C31, C32: 0.047uF; C_0603_1608Metric; MPN VJ0603Y473JXQPW1BC; Mouser SPN 77-VJ0603Y473JXQPBC
C34: 1000pF; C_0603_1608Metric; MPN GRM1885C1H102JA01J; Mouser SPN 81-GRM1885C1H102JA1J
C_THERM1: NTC_CHGR; Molex_Pico-Clasp_203558-0207_1x02-1MP_P1.00mm_Horizontal; MPN 203558-0207; Mouser SPN 538-203558-0207
L1: 2.2uH; L_Wurth_WE-LHMI-7030; MPN 74437346022; Mouser SPN 710-74437346022
NTC1: 10 k; PinHeader_1x02_P2.54mm_Vertical; MPN 103AT-2; Mouser SPN 954-103AT-2; not fitted
POWER1, POWER2, POWER3: 218989-0210; CONN02_2189890210_MOL; MPN 218989-0210; Mouser SPN 538-218989-0210; not fitted
R5: 27k; R_0603_1608Metric; MPN RCS060327K0FKEA; Mouser SPN 71-RCS060327K0FKEA
R6: 127k; R_0603_1608Metric; MPN CRCW0603127KFKEA; Mouser SPN 71-CRCW0603-127K-E3
R7: 48.7k; R_0603_1608Metric; MPN CRCW060348K7FKEA; Mouser SPN 71-CRCW0603-48.7K-E3
R8: 100; R_0603_1608Metric; MPN RCS0603100RFKEA; Mouser SPN 71-RCS0603100RFKEA
R9: 301; R_0603_1608Metric; MPN RCS0603301RFKEA; Mouser SPN 71-RCS0603301RFKEA
R19, R20: 10k; R_0603_1608Metric; MPN RCS060310K0FKEA; Mouser SPN 71-RCS060310K0FKEA; not fitted
R21: 5.36k; R_0603_1608Metric; MPN CRCW06035K36FKEA; Mouser SPN 71-CRCW0603-5.36K-E3
R22: 30.9k; R_0603_1608Metric; MPN CRCW060330K9FKEA; Mouser SPN 71-CRCW0603-30.9K-E3
STAT1: Green; LED_0805_2012Metric; MPN 150080GS75000; Mouser SPN 710-150080GS75000
U3: BQ25798RQMR; VQFN-HR-RQM-29; MPN BQ25798RQMR; Mouser SPN 595-BQ25798RQMR

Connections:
/Battery Charger/+PACK: BAT_CON1.1, C49.1, C50.1, C51.1, R8.1, U3.22 (BAT), U3.23 (BAT); also elsewhere on the board
/Battery Charger/BATP: C30.1, R8.2, U3.18 (BATP)
/Battery Charger/BTST1: C31.2, U3.4 (BTST1)
/Battery Charger/BTST2: C32.1, U3.19 (BTST2)
/Battery Charger/I2Cc.SCA: U3.15 (SDA); also elsewhere on the board
/Battery Charger/I2Cc.SCL: U3.14 (SCL); also elsewhere on the board
/Battery Charger/ILIM_HIZ: R6.2, R7.1, U3.17 (ILIM_HIZ)
/Battery Charger/PROG: R5.1, U3.20 (PROG)
/Battery Charger/REGN: C27.1, R6.1, R9.2, R20.2, R21.1, U3.5 (REGN)
/Battery Charger/SDRV: C34.1, U3.24 (SDRV)
/Battery Charger/STAT: STAT1.1 (K), U3.1 (STAT)
/Battery Charger/SW1: C31.1, L1.1, U3.28 (SW1)
/Battery Charger/SW2: C32.2, L1.2, U3.26 (SW2)
/Battery Charger/SYS: C29.1, C33.1, C35.1, C36.1, C37.1, C38.1, POWER1.1, POWER2.1, POWER3.1, U3.25 (SYS); also elsewhere on the board
/Battery Charger/THERM: C_THERM1.2, NTC1.1, R19.1, R20.1, R21.2, R22.1, U3.16 (TS)
/Battery Charger/USYS: C19.1, C21.1, C23.1, C25.1, U3.29 (PMID)
/GND: BAT_CON1.2, C19.2, C20.2, C21.2, C22.2, C23.2, C24.2, C25.2, C26.2, C27.2, C28.2, C29.2, C30.2, C33.2, C34.2, C35.2, C36.2, C37.2, C38.2, C49.2, C50.2, C51.2, C_THERM1.1, C_THERM1.MP (MountPin), NTC1.2, POWER1.2, POWER2.2, POWER3.2, R5.2, R7.2, R19.2, R22.2, U3.10 (ACDRV2), U3.11 (ACDRV1), U3.13 (CE_N), U3.27 (GND); also elsewhere on the board
/PPHV: C20.1, C22.1, C24.1, C26.1, C28.1, U3.2 (VBUS), U3.3 (VBUS), U3.8 (VAC2), U3.9 (VAC1); also elsewhere on the board
unnamed: R9.1, STAT1.2 (A)

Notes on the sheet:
Optional Uninterrupted System Load
INPUT_CURRENT_LIMIT
18650 Battery 3.7 Volt Lithium 3300mAh Charging Voltage: 4.2V Charging Current: Configuration: 4S 14.8V - 16.8V
System Load (11.9-16.8V)
CHARGER_CONFIG
Thermistor Offboard
5V, 30 mA Internal Regulator Output
I2C Connection to PD Controller
If TS function is not used, connect divider to set V on TS to 50% REGN.
GND = Disable Ship Mode
Charger Input Voltage from PPHV
TPS25751 will disable limit after POR and set new limit.
GND = Change Enable
Thermistor Disabled
Power-On-Reset Default Settings At power up, the charger detects the resistance tied to PROG pin to determine the default switching frequency and the default battery charging profile. 4.7 kΩ = 1S Battery Config 8.2 kΩ = 2S Battery Config 13.7 kΩ = 3S Battery Config 27.0 kΩ = 4S Battery Config
482mA IINDPM
Temperature qualification voltage input
CONNECTORS
BATTERY

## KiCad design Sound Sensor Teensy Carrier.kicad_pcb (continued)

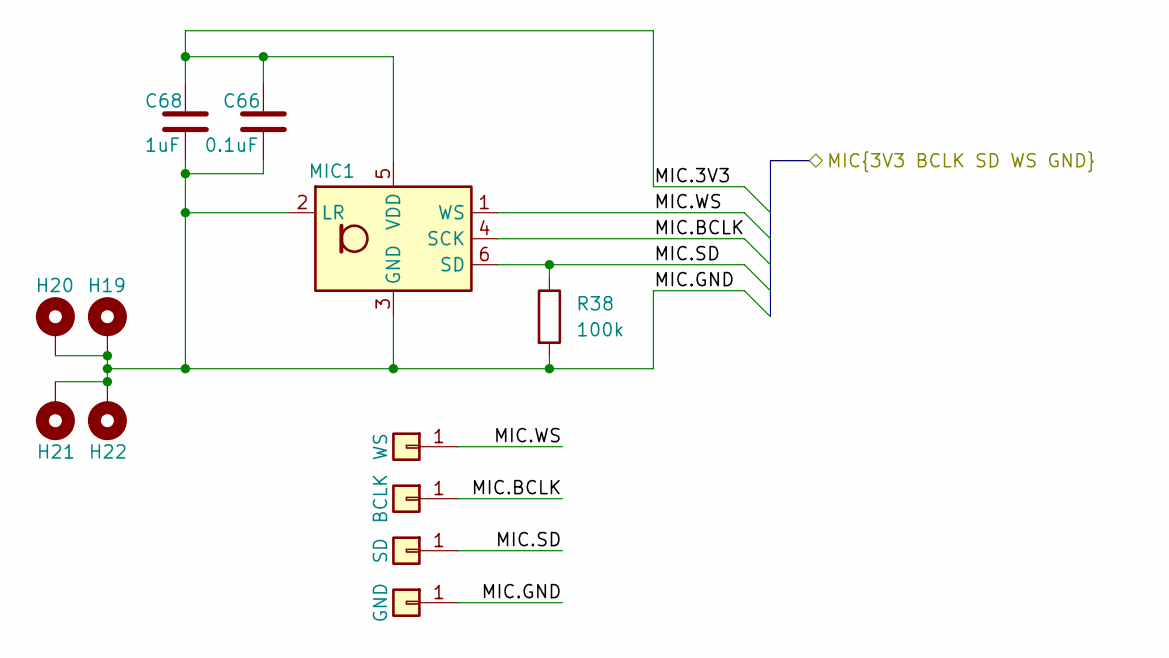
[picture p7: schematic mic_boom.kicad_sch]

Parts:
C66: 0.1uF; C_0603_1608Metric; MPN GCM188R71H104KA57J; Mouser SPN 81-GCM188R71H104KA7J
C68: 1uF; C_0603_1608Metric; MPN 06035C105KAT2A; Farnell SPN 4155078
H19, H20, H21, H22: MountingHole_Pad; MountingHole_2.2mm_M2_Pad
H35: WS; SolderWirePad_1x01_SMD_1x2mm
H36: BCLK; SolderWirePad_1x01_SMD_1x2mm
H37: SD; SolderWirePad_1x01_SMD_1x2mm
H38: GND; SolderWirePad_1x01_SMD_1x2mm
MIC1: ICS-43434; InvenSense_ICS-43434-6_3.5x2.65mm; MPN ICS-43434; Mouser SPN 410-ICS-43434
R38: 100k; R_0603_1608Metric; MPN RCS0603100KFKEA; Mouser SPN 71-RCS0603100KFKEA

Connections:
/Mic Boom/MIC.3V3: C66.1, C68.1, MIC1.5 (VDD); also elsewhere on the board
/Mic Boom/MIC.BCLK: H36.1, MIC1.4 (SCK); also elsewhere on the board
/Mic Boom/MIC.GND: C66.2, C68.2, H19.1, H20.1, H21.1, H22.1, H38.1, MIC1.2 (LR), MIC1.3 (GND), R38.2; also elsewhere on the board
/Mic Boom/MIC.SD: H37.1, MIC1.6 (SD), R38.1; also elsewhere on the board
/Mic Boom/MIC.WS: H35.1, MIC1.1 (WS); also elsewhere on the board

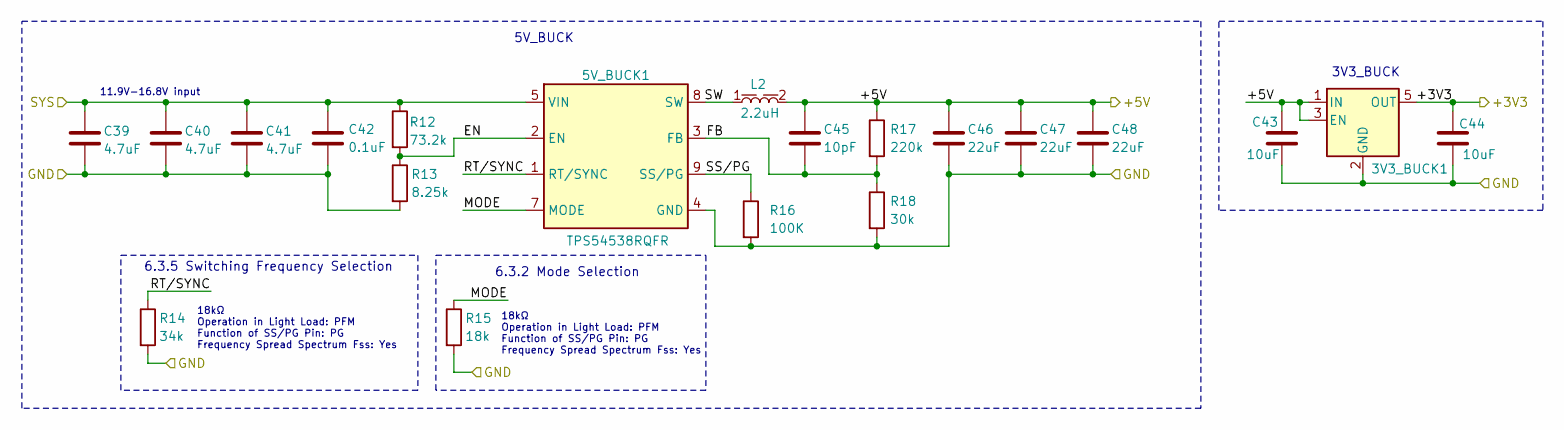
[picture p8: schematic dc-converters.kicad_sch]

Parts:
3V3_BUCK1: 3.3V; SOT-23-5; MPN TLV75533PDBVR; Mouser SPN 595-TLV75533PDBVR
5V_BUCK1: TPS54538RQFR; VQFN-HR-RQF-9; MPN TPS54538RQFR; Mouser SPN 595-TPS54538RQFR
C39, C40, C41: 4.7uF; C_0603_1608Metric; MPN GRM188R6YA475KE15D; Mouser SPN 81-GRM188R6YA475KE5D
C42: 0.1uF; C_0603_1608Metric; MPN GCM188R71H104KA57J; Mouser SPN 81-GCM188R71H104KA7J
C43, C44: 10uF; C_0603_1608Metric; MPN GRM188R6YA106MA73D; Mouser SPN 81-GRM188R6YA106MA3D
C45: 10pF; C_0603_1608Metric; MPN 06033A100FAT2A; Mouser SPN 581-06033A100FAT2A
C46, C47, C48: 22uF; C_0603_1608Metric; MPN GRM188R61A226ME15J; Mouser SPN 81-GRM188R61A226ME5J
L2: 2.2uH; L_Wurth_WE-LHMI-7030; MPN 74437346022; Mouser SPN 710-74437346022
R12: 73.2k; R_0603_1608Metric; MPN CRCW060373K2FKEA; Mouser SPN 71-CRCW0603-73.2K-E3
R13: 8.25k; R_0603_1608Metric; MPN CRCW06038K25FKEA; Mouser SPN 71-CRCW0603-8.25K-E3
R14: 34k; R_0603_1608Metric; MPN CRCW060334K0FKEA; Mouser SPN 71-CRCW0603-34K-E3
R15: 18k; R_0603_1608Metric; MPN CRCW060318K0FKEA; Mouser SPN 71-CRCW0603-18K-E3
R16: 100K; R_0603_1608Metric; MPN RCS0603100KFKEA; Mouser SPN 71-RCS0603100KFKEA
R17: 220k; R_0603_1608Metric; MPN RCS0603220KFKEA; Mouser SPN 71-RCS0603220KFKEA
R18: 30k; R_0603_1608Metric; MPN CRCW060330K0FKEA; Mouser SPN 71-CRCW0603-30K-E3

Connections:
/+3V3: 3V3_BUCK1.5 (OUT), C44.1; also elsewhere on the board
/+5V: 3V3_BUCK1.1 (IN), 3V3_BUCK1.3 (EN), C43.1, C45.1, C46.1, C47.1, C48.1, L2.2, R17.1; also elsewhere on the board
/Battery Charger/SYS: 5V_BUCK1.5 (VIN), 5V_BUCK1.6 (VIN), C39.1, C40.1, C41.1, C42.1, R12.1; also elsewhere on the board
/DC Converters/EN: 5V_BUCK1.2 (EN), R12.2, R13.1
/DC Converters/FB: 5V_BUCK1.3 (FB), C45.2, R17.2, R18.1
/DC Converters/MODE: 5V_BUCK1.7 (MODE), R15.1
/DC Converters/SS/PG: 5V_BUCK1.9 (SS/PG), R16.1
/DC Converters/SW: 5V_BUCK1.8 (SW), L2.1
/GND: 3V3_BUCK1.2 (GND), 5V_BUCK1.4 (GND), C39.2, C40.2, C41.2, C42.2, C43.2, C44.2, C46.2, C47.2, C48.2, R13.2, R14.2, R15.2, R16.2, R18.2; also elsewhere on the board

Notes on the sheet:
18kΩ Operation in Light Load: PFM Function of SS/PG Pin: PG Frequency Spread Spectrum Fss: Yes
6.3.2 Mode Selection
3V3_BUCK
11.9V-16.8V input
6.3.5 Switching Frequency Selection
5V_BUCK

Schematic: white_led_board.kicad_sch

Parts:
C67, C76: 22uF; C_0805_2012Metric; MPN C2012X5R1V226M125AC; DigiKey SPN 445-14428-2-ND
C69, C72: 1uF; C_0603_1608Metric; MPN 06035C105KAT2A; Mouser SPN 581-06035C105KAT2A
C70, C71, C77: 0.1uF; C_0603_1608Metric; MPN GCM188R71H104KA57J; Mouser SPN 81-GCM188R71H104KA7J
C74: 1nF; C_0603_1608Metric; MPN GRM1885C1H102JA01J; Mouser SPN 81-GRM1885C1H102JA1J
C_{FLT}73: 1nF; C_0603_1608Metric; MPN GRM1885C1H102JA01J; Mouser SPN 81-GRM1885C1H102JA1J
C_{SNS}75: 1uF; C_0603_1608Metric; MPN 06035C105KAT2A; Mouser SPN 581-06035C105KAT2A
D3: 700mV; TO-277A; MPN STPST10H100SFY; DigiKey SPN 497-STPST10H100SFYTR-ND
D4, D5, D6, D7, D8, D9, D10, D11, D12, D13, D14, D15, D16, D17, D18, D19, D20, D21, D22, D23, D24, D25, D26, D27, D28, D29, D30, D31, D32, D33, D34, D35, D36, D37, D38, D39, D40, D41, D42, D43, D44, D45, D46, D47, D48, D49, D50, D51: 158302250; D_Wurth_WL-SWTP_3022; MPN 158302250; Mouser SPN 710-158302250
L4: 10uH; L_Wurth_WE-HCI-7050; Part Number 744314101; Farnell UK SPN 1890614
R40: 100; R_0603_1608Metric; MPN RCS0603100RFKEA; Mouser SPN 71-RCS0603100RFKEA
R41: 40.2k; R_0603_1608Metric; MPN RCS060340K2FKEA; DigiKey SPN 541-10468-2-ND
R44: 1.1M; R_0603_1608Metric; MPN CRCW06031M10FKEA; DigiKey SPN 541-5250-2-ND
R45: 48.7k; R_0603_1608Metric; MPN CRCW060348K7FKEA; Mouser SPN 71-CRCW0603-48.7K-E3
R46: 18k; R_0603_1608Metric; MPN CRCW060318K0FKEA; Mouser SPN 71-CRCW0603-18K-E3
R_{FLT}39: 100; R_0603_1608Metric; MPN RCS0603100RFKEA; Mouser SPN 71-RCS0603100RFKEA
R_{FSET}42: 27k; R_0603_1608Metric; MPN RCS060327K0FKEA; Mouser SPN 71-RCS060327K0FKEA; not fitted
R_{SNS}43: 560m; R_0805_2012Metric; MPN ERJ-6DQFR56V; Mouser SPN 667-ERJ-6DQFR56V
U5: TPS923652DRRR; Texas_DRR0012C_WSON-12-DRR_0.8mm; MPN TPS923652DRRR; DigiKey SPN 296-TPS923652DRRRTR-ND

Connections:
/White LED Board/+VLED: C76.1, C77.1, C_{SNS}75.1, D4.2 (+), D12.2 (+), D20.2 (+), D28.2 (+), D36.2 (+), D44.2 (+), R44.1, R_{FLT}39.2, R_{SNS}43.2
/White LED Board/ADIM: U5.3 (ADIM); also elsewhere on the board
/White LED Board/COMP: R40.1, U5.8 (COMP)
/White LED Board/CSN: C_{FLT}73.2, R_{FLT}39.1, U5.10 (CSN)
/White LED Board/CSP: C_{FLT}73.1, C_{SNS}75.2, D3.3 (K), R_{SNS}43.1, U5.11 (CSP)
/White LED Board/FSET: R46.1, R_{FSET}42.1, U5.7 (FSET)
/White LED Board/GND: C67.1, C69.2, C70.2, C71.2, C72.2, C74.2, C76.2, C77.2, D4.3 (PAD), D5.3 (PAD), D6.3 (PAD), D7.3 (PAD), D8.3 (PAD), D9.3 (PAD), D10.3 (PAD), D11.1 (-), D11.3 (PAD), D12.3 (PAD), D13.3 (PAD), D14.3 (PAD), D15.3 (PAD), D16.3 (PAD), D17.3 (PAD), D18.3 (PAD), D19.1 (-), D19.3 (PAD), D20.3 (PAD), D21.3 (PAD), D22.3 (PAD), D23.3 (PAD), D24.3 (PAD), D25.3 (PAD), D26.3 (PAD), D27.1 (-), D27.3 (PAD), D28.3 (PAD), D29.3 (PAD), D30.3 (PAD), D31.3 (PAD), D32.3 (PAD), D33.3 (PAD), D34.3 (PAD), D35.1 (-), D35.3 (PAD), D36.3 (PAD), D37.3 (PAD), D38.3 (PAD), D39.3 (PAD), D40.3 (PAD), D41.3 (PAD), D42.3 (PAD), D43.1 (-), D43.3 (PAD), D44.3 (PAD), D45.3 (PAD), D46.3 (PAD), D47.3 (PAD), D48.3 (PAD), D49.3 (PAD), D50.3 (PAD), D51.1 (-), D51.3 (PAD), R41.2, R45.2, U5.5 (nFault), U5.13 (GND), U5.14 (GND), U5.15 (GND), U5.16 (GND), U5.17 (GND); also elsewhere on the board
/White LED Board/OVP: R44.2, R45.1, U5.9 (OVP)
/White LED Board/PWM: U5.4 (PWM); also elsewhere on the board
/White LED Board/SW: D3.1 (A), D3.2 (A), L4.2, U5.12 (SW)
/White LED Board/TEMP: R41.1, U5.6 (TEMP)
/White LED Board/VCC: C72.1, U5.2 (VCC)
/White LED Board/VIN: C67.2, C69.1, C70.1, C71.1, L4.1, U5.1 (VIN); also elsewhere on the board
unnamed: C74.1, R40.2
unnamed: D4.1 (-), D5.2 (+)
unnamed: D5.1 (-), D6.2 (+)
unnamed: D6.1 (-), D7.2 (+)
unnamed: D7.1 (-), D8.2 (+)
unnamed: D8.1 (-), D9.2 (+)
unnamed: D9.1 (-), D10.2 (+)
unnamed: D10.1 (-), D11.2 (+)
unnamed: D12.1 (-), D13.2 (+)
unnamed: D13.1 (-), D14.2 (+)
unnamed: D14.1 (-), D15.2 (+)
unnamed: D15.1 (-), D16.2 (+)
unnamed: D16.1 (-), D17.2 (+)
unnamed: D17.1 (-), D18.2 (+)
unnamed: D18.1 (-), D19.2 (+)
unnamed: D20.1 (-), D21.2 (+)
unnamed: D21.1 (-), D22.2 (+)
unnamed: D22.1 (-), D23.2 (+)
unnamed: D23.1 (-), D24.2 (+)
unnamed: D24.1 (-), D25.2 (+)
unnamed: D25.1 (-), D26.2 (+)
unnamed: D26.1 (-), D27.2 (+)
unnamed: D28.1 (-), D29.2 (+)
unnamed: D29.1 (-), D30.2 (+)
unnamed: D30.1 (-), D31.2 (+)
unnamed: D31.1 (-), D32.2 (+)
unnamed: D32.1 (-), D33.2 (+)
unnamed: D33.1 (-), D34.2 (+)
unnamed: D34.1 (-), D35.2 (+)
unnamed: D36.1 (-), D37.2 (+)
unnamed: D37.1 (-), D38.2 (+)
unnamed: D38.1 (-), D39.2 (+)
unnamed: D39.1 (-), D40.2 (+)
unnamed: D40.1 (-), D41.2 (+)
unnamed: D41.1 (-), D42.2 (+)
unnamed: D42.1 (-), D43.2 (+)
unnamed: D44.1 (-), D45.2 (+)
unnamed: D45.1 (-), D46.2 (+)
unnamed: D46.1 (-), D47.2 (+)
unnamed: D47.1 (-), D48.2 (+)
unnamed: D48.1 (-), D49.2 (+)
unnamed: D49.1 (-), D50.2 (+)
unnamed: D50.1 (-), D51.2 (+)
unnamed: R46.2, R_{FSET}42.2

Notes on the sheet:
7.3.8 Thermal Foldback
Switching Freq Resistor 0.1 MHz = 160 kΩ 0.2 MHz = 95 kΩ 0.3 MHz = 67 kΩ 0.4 MHz = 52 kΩ 0.5 MHz = 43.5 kΩ 0.6 MHz = 35 kΩ 0.8 MHz = 27 kΩ 1.0 MHz = 21 kΩ 1.2 MHz = 18 kΩ 1.5 MHz = 14 kΩ 1.8 MHz = 11 kΩ 2.2 MHz = 9.2 kΩ

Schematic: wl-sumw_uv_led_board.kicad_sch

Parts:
C73, C79: 0.1uF; C_0603_1608Metric; MPN GCM188R71H104KA57J; Mouser SPN 81-GCM188R71H104KA7J
C75, C78: 10uF; C_0603_1608Metric; MPN GRM188R6YA106MA73D; Mouser SPN 81-GRM188R6YA106MA3D
D52, D53: 3535 UV-A; D_Wurth_WL-SUMW_3535_153353XXAA350; MPN 15335337AA350; Mouser SPN 710-15335337AA350
H28: PWM; SolderWirePad_1x01_SMD_1.5x3mm; not fitted
H29: VIN; SolderWirePad_1x01_SMD_2x4mm; not fitted
H30: GND; SolderWirePad_1x01_SMD_2x4mm; not fitted
H31, H32, H33, H34: MountingHole_Pad; MountingHole_2.2mm_M2_Pad
L3: 8.2uH; L_Wurth_WE-MAIA-4030; MPN 78438357082; DigiKey SPN 732-11745-2-ND
R_{fb}1: 0; R_0603_1608Metric; MPN RCC06030000Z0EA; Mouser SPN 71-RCC06030000Z0EA
R_{sns}2: 0.143; R_0603_1608Metric; MPN SR731JTTDR143F; DigiKey SPN 2019-SR731JTTDR143FTR-ND
U6: TPS92200D2DDCR; SOT-23-6; MPN TPS92200D2DDCR; DigiKey SPN 296-TPS92200D2DDCRTR-ND

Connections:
/WL-SUMW UV LED Board/BOOT: C73.2, U6.6 (BOOT)
/WL-SUMW UV LED Board/FB: R_{fb}1.1, U6.1 (FB)
/WL-SUMW UV LED Board/GND: C75.2, C78.2, C79.2, D52.3 (THERM), D53.3 (THERM), H31.1, H32.1, H33.1, H34.1, R_{sns}2.2, U6.3 (GND); also elsewhere on the board
/WL-SUMW UV LED Board/PWM: H28.1, U6.2 (DIM); also elsewhere on the board
/WL-SUMW UV LED Board/SENSE: D53.1 (C), R_{fb}1.2, R_{sns}2.1
/WL-SUMW UV LED Board/SW: C73.1, L3.1, U6.5 (SW)
/WL-SUMW UV LED Board/VIN: C78.1, C79.1, U6.4 (VIN); also elsewhere on the board
/WL-SUMW UV LED Board/VOUT: C75.1, D52.2 (A), L3.2
unnamed: D52.1 (C), D53.2 (A)

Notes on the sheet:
7.3.2 Setting LED Current: R_{SNS} = V_{FB_REF} / I_{LED} V_{FB_REF} is fixed at 0.099 V, I_{LED} = 0.700 A 0.099 / 0.700 = 141 mΩ (next common size = 143 mΩ)
Used to measure the loop response
Passthrough Connection

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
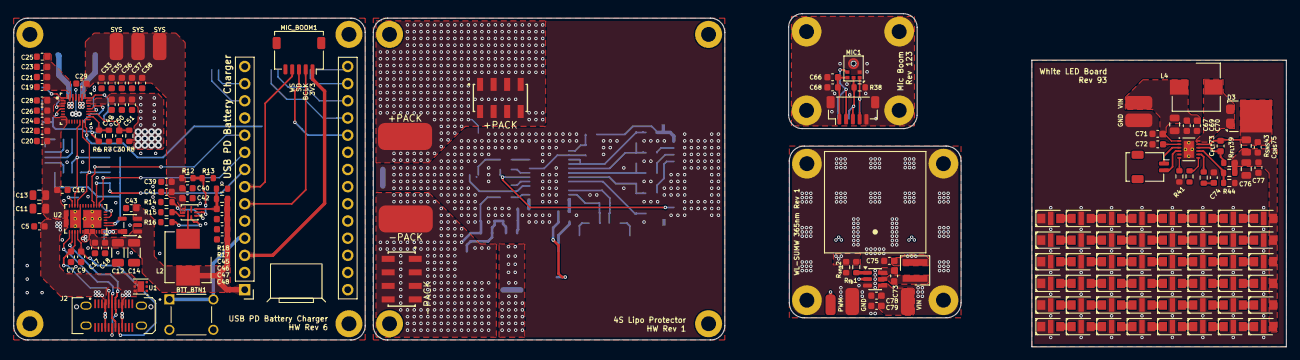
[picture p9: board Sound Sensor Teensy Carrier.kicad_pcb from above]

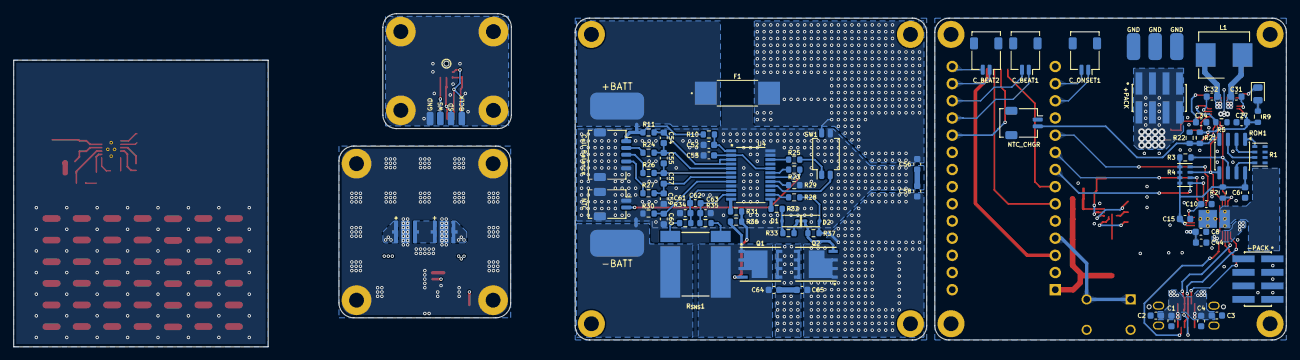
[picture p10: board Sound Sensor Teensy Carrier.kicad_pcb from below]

Board: 4 copper layers, 188.3 x 49.3 mm, 257 parts (84 on the bottom side), 160 nets.

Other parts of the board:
B1, B2, B3, B4, B6: Board

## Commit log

2026-04-01 Initial commit of design.
    [Sound Sensor Teensy Carrier.kicad_pcb, Sound Sensor Teensy Carrier.kicad_sch, battery-charger.kicad_sch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]
2026-04-01 Add `separate.zsh` script for PCB component extraction automation
